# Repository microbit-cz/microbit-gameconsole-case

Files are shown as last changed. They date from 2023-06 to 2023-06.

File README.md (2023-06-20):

 # Micro:bit "Reaction game" cover for Micro:bit V2 IO Expansion Board

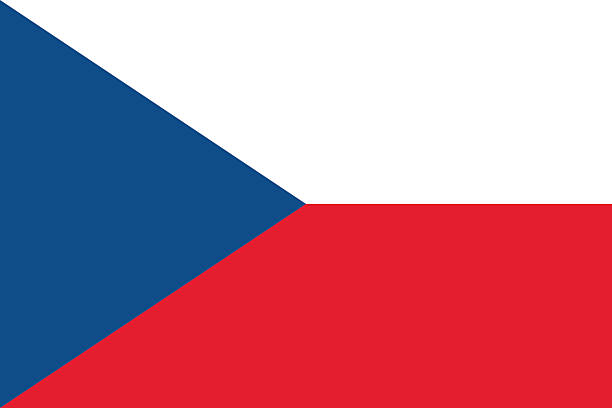
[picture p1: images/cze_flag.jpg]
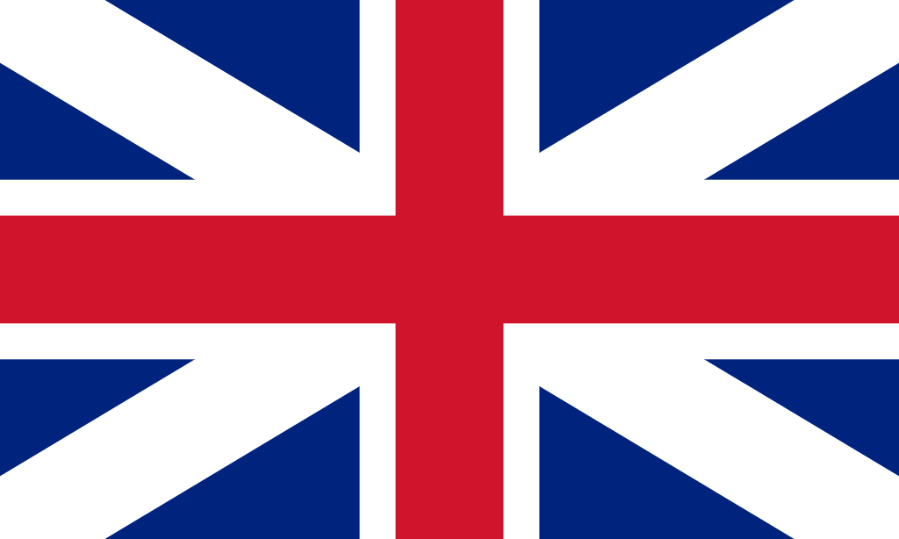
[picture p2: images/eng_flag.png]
[](./README_CZ.md) [](./README.md)

<p align="center">
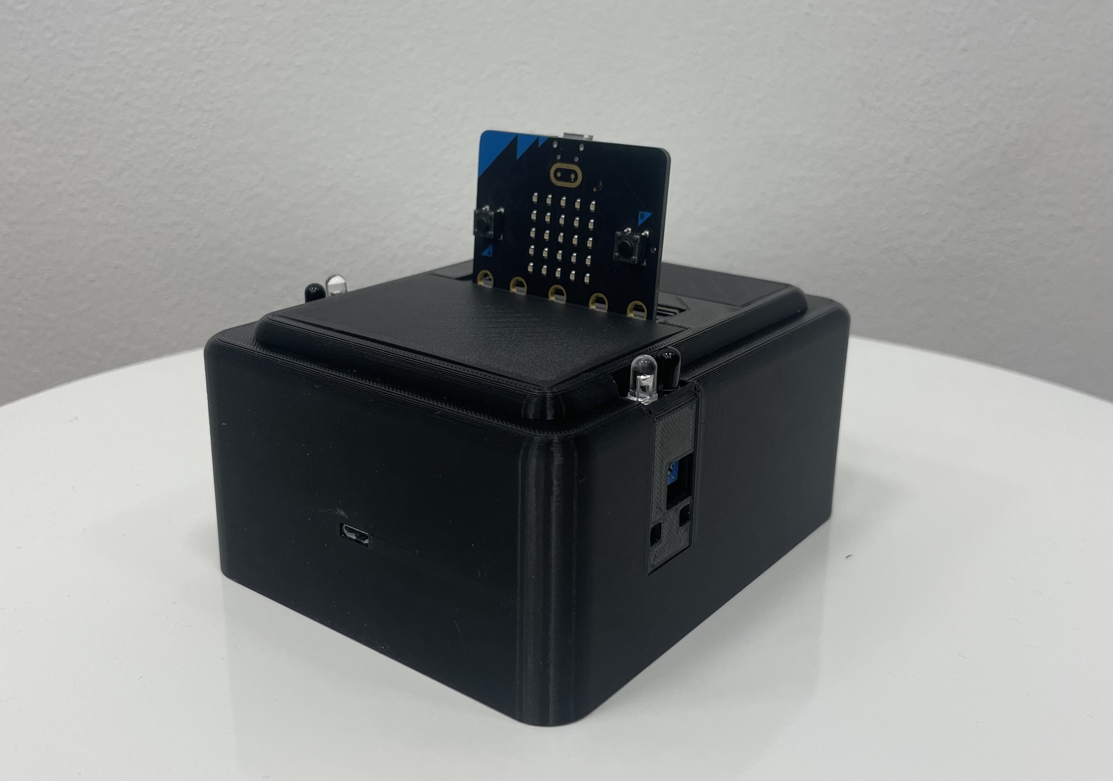
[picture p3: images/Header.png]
   
</p>

## Reaction game
### How does this game work?
A game for two players. The game engine displays an "icon" on the LEDs after a randomly long time (3-10 s) after the game restarts, and at the same time (without delay) starts a tone of 1.5 s. This indicates the start of the game. The player's task is to press the "button" before the opponent. The "button" can be pressed immediately after the LEDs are lit, while the tone is still sounding.
### Results
- Player 1 was faster → then the display shows "1"
- Faster was player 2 → then display shows "2"
- They both pressed the "button" at the same moment (within the computer's reaction time) → then the display shows "R" → Draw
- Player 1 pressed the "button" one or more times before the game started → then the display shows "B"	
- Player 2 has pressed the "button" one or more times before the game starts → then the display shows "A"
- Both players have pressed the "button" one or more times before the game starts → then the display shows "C" → Cheater
  
  [Code here](https://github.com/pslib-cz/2022-p2a-mme-pppp-Lukypop/blob/main/pxt-reaction-game-as-txt.txt)
  
## Tips & Tricks

- [Installing heat nuts](https://markforged.com/resources/blog/heat-set-inserts)
- [Cable crimping](https://ratrig.dozuki.com/Guide/11.+Cable+Crimping/80)
- [Soldering](https://www.makerspaces.com/how-to-solder/)

## What do you need?

- Micro:bit extension [Micro:bit V2 IO Expansion Board](https://www.aliexpress.com/item/1005002353248507.html)
- 2 pieces of [Insert Nut M3](https://www.aliexpress.com/item/1005004701945081.html)
- 2 pieces of [IR sensor](https://www.aliexpress.com/item/1297063929.html)
- 1 piece of [Batery Holder AA](https://www.aliexpress.com/item/1005002927831106.html)
- 1 piece of [Vertical micro USB ](https://www.aliexpress.com/item/1005002650191316.html)
- 1 piece of [Micro USB connector](https://www.aliexpress.com/item/32267930530.html)
- ~150 grams of filament ABS
- 1× 2-way cable (9 cm)
- 2× 3-way crimped cables (10 cm)
- 2× LEGO part 2780 [example](https://www.amazon.co.uk/Technic-Friction-Ridges-Lengthwise-Center/dp/B01N6WURXK/)

## Embedding parts
### Step 1:
- download and print [parts](https://github.com/pslib-cz/2022-p2a-mme-pppp-Lukypop/tree/main/parts) or [parts as STL](https://github.com/pslib-cz/2022-p2a-mme-pppp-Lukypop/tree/main/parts/STL) using a 3d printer
### Step 2:
- insert heat nuts on both sides
  
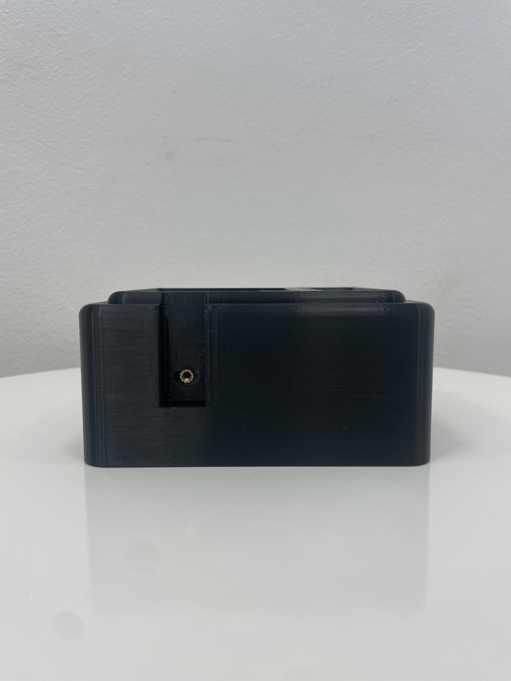
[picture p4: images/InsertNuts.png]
   

### Step 3:
- Insert lego parts into the holes
- Place Micro:bit V2 IO Expansion Board on these parts
  
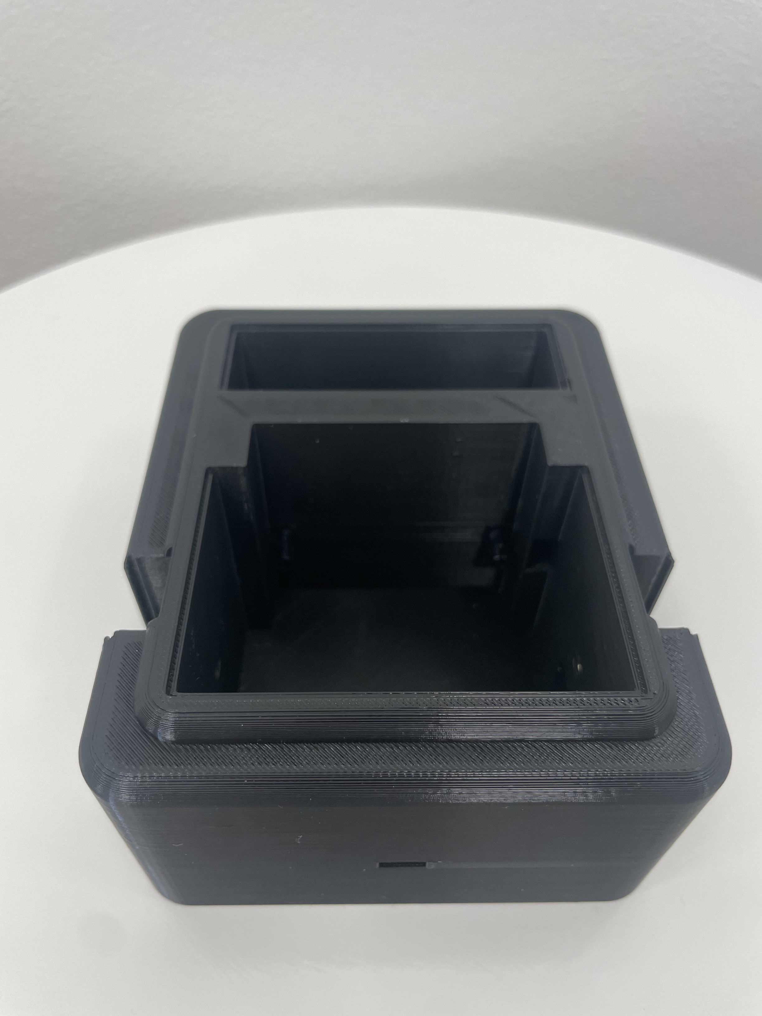
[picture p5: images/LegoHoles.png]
    
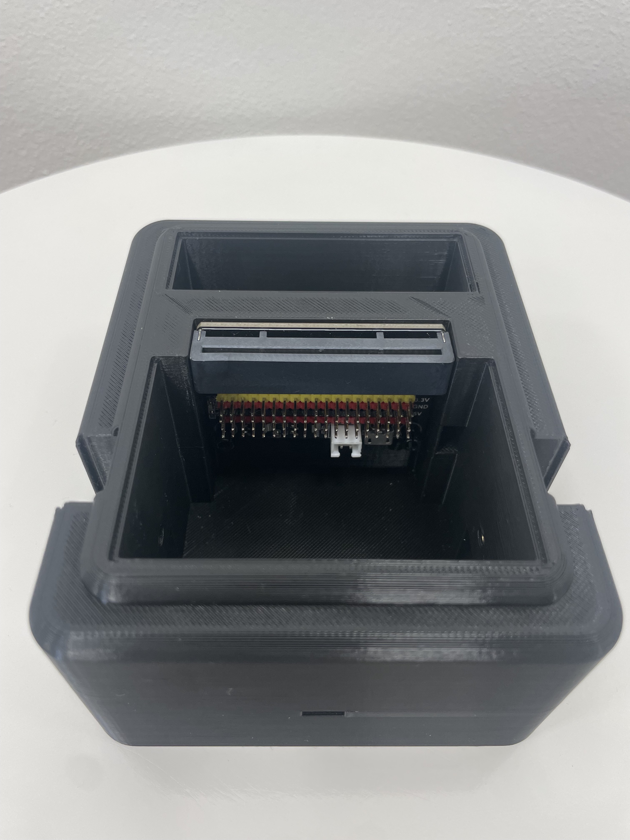
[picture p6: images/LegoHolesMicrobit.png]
    

### Step 4:
- Connect IR sensor to 3-way crimped cable and put it through hole
- Screw the M3 bolt to hold IR sensor into insert nut

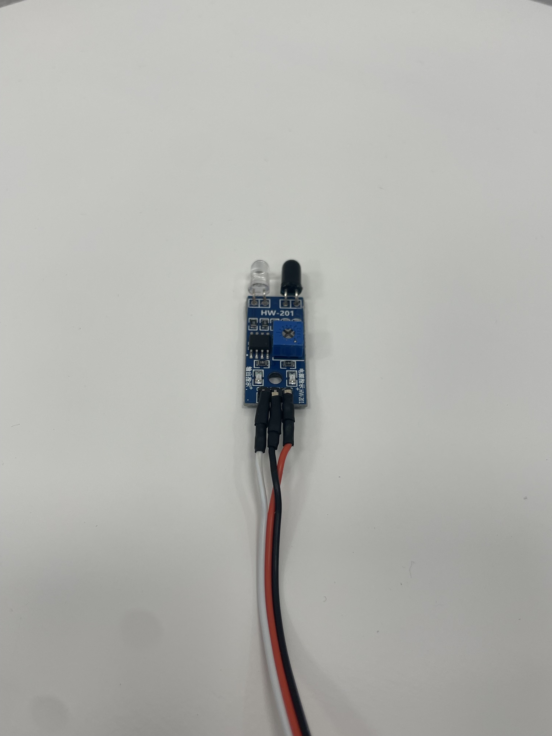
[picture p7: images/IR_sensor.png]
   
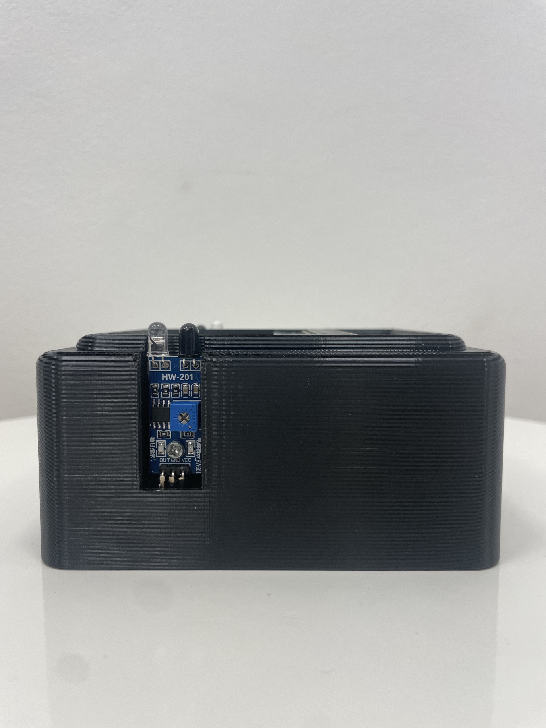
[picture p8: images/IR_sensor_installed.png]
   
 
- Slide sensor lid into thin hole
- Do "Step 4" on both sides

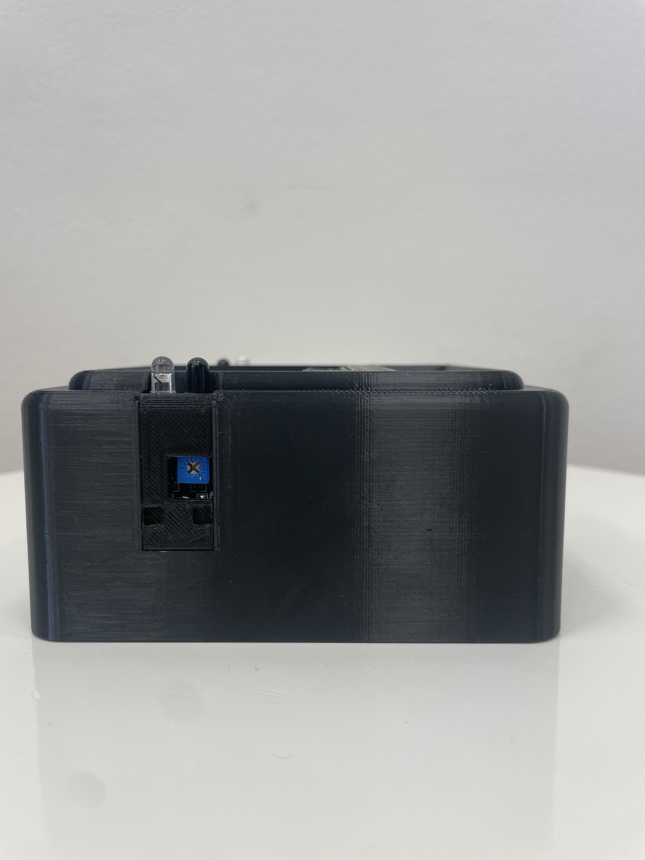
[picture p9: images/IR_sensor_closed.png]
   
  
- Connect 3-way crimped cables to Micro:bit V2 IO Expansion Board on pins: 1, 2 (see image)

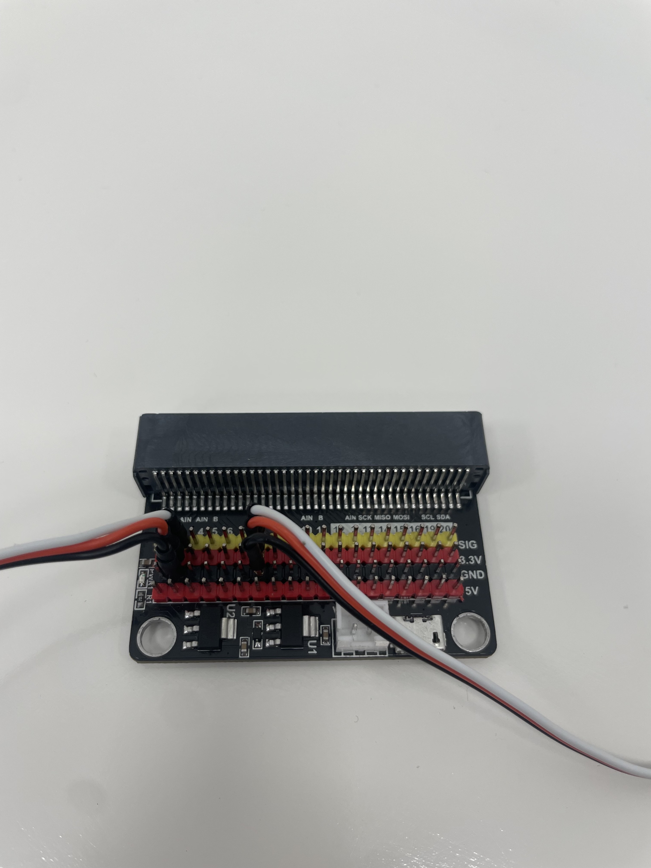
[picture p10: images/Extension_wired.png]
    
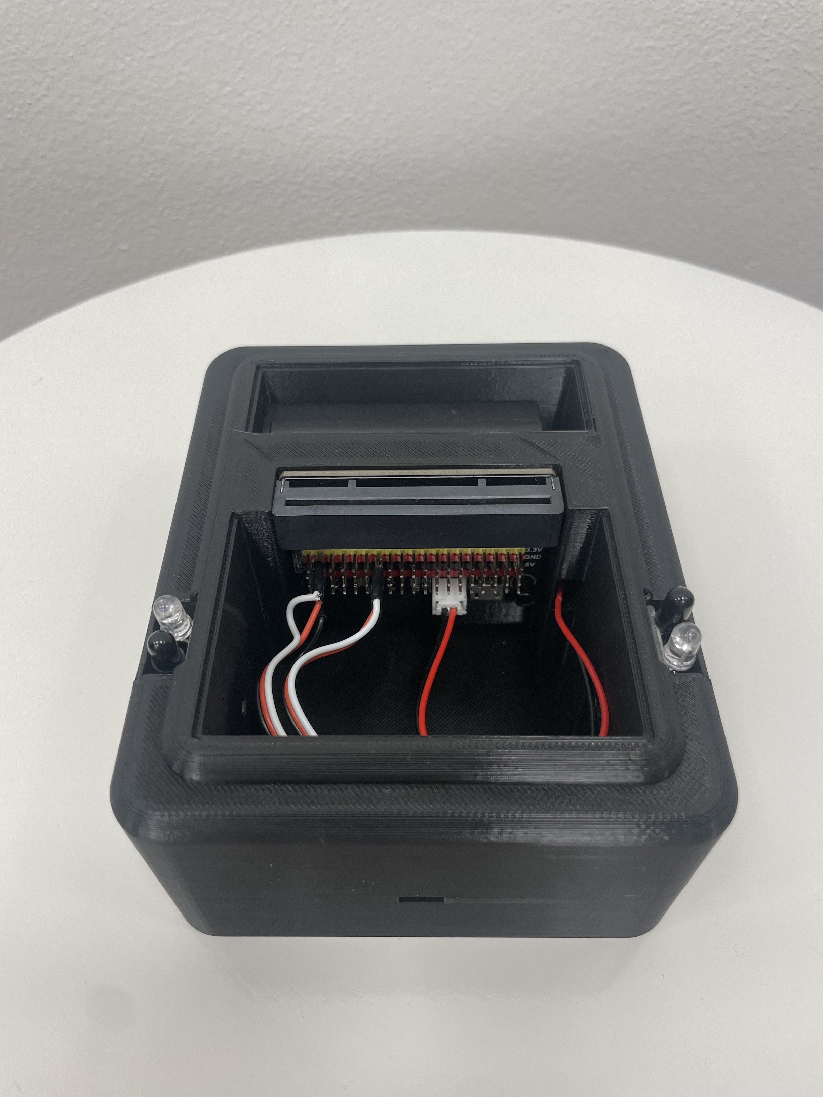
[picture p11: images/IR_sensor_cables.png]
    

### Step 5:
- Put battery holder cable through hole
- Connect it into Micro:bit V2 IO Expansion Board (into [JST-PH plug](./images/JST_plug.jpg))
- Place battery holder in storage place

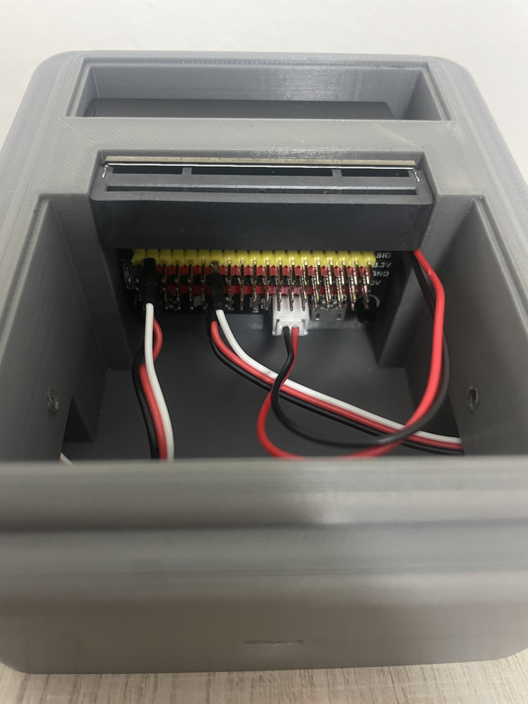
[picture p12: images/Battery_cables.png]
   
   
### Step 6:
- Connect 2-way cable with vertical micro USB plug and micro USB connector using soldering
- Be careful about + and - ([see image](https://github.com/pslib-cz/2022-p2a-mme-pppp-Lukypop/blob/main/images/micro_usb_wiring.png) if you are not sure)

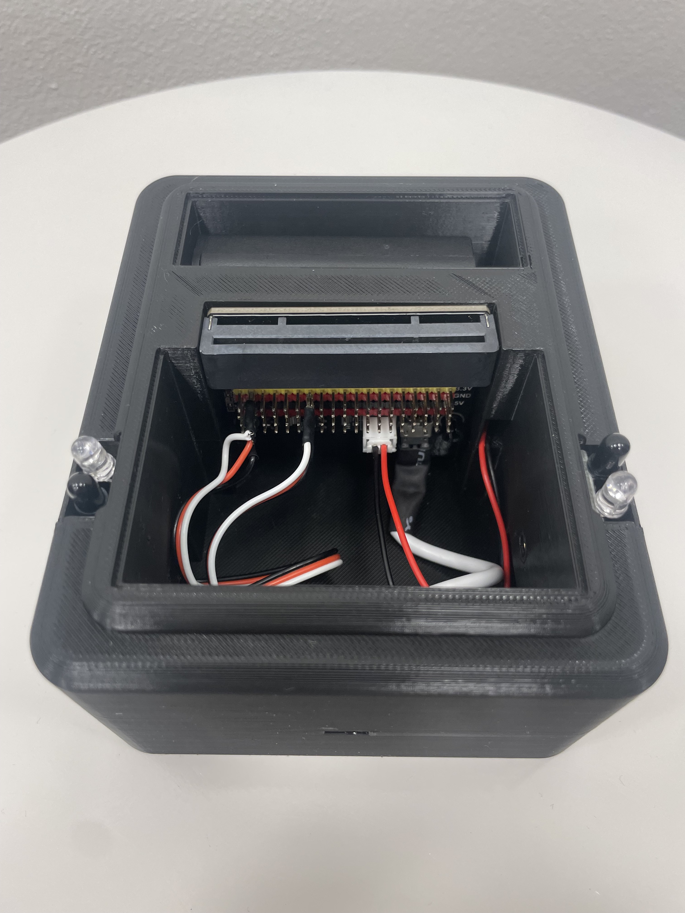
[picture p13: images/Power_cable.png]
    

- Connect micro USB into Micro:bit V2 IO Expansion Board and glue vertical micro USB plug into pre-made hole

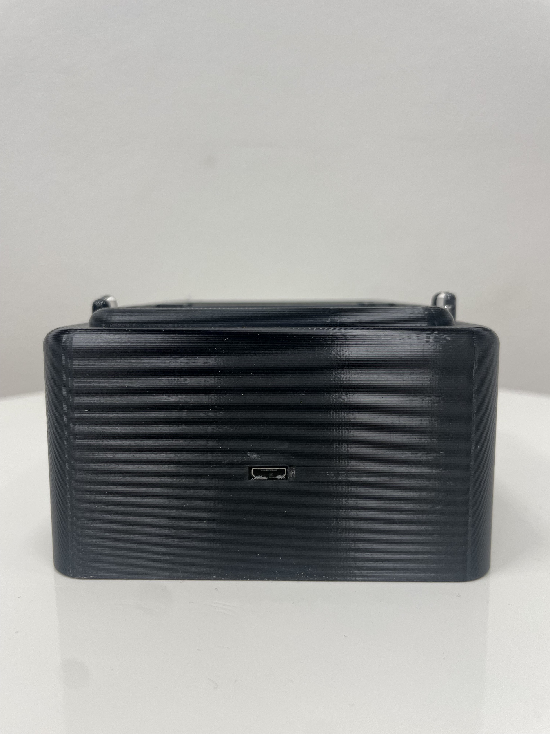
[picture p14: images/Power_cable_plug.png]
      
      
- Close both storage places with lids

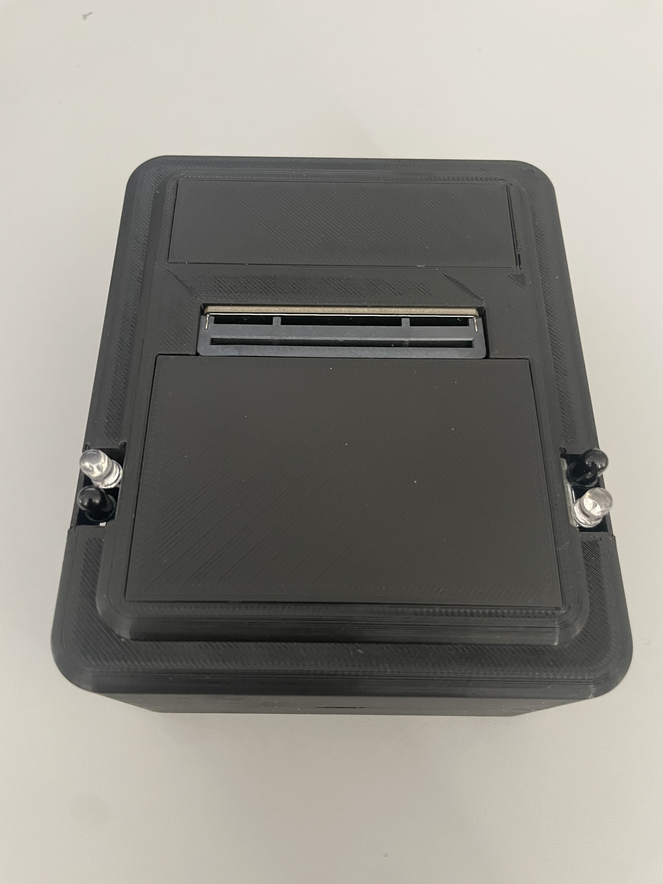
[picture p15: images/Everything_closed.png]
      
     
### Step 7:
- Upload the code to the micro:bit [code here](https://github.com/pslib-cz/2022-p2a-mme-pppp-Lukypop/blob/main/microbit-pxt-reaction-game.hex) or [as .txt here](https://github.com/pslib-cz/2022-p2a-mme-pppp-Lukypop/blob/main/pxt-reaction-game-as-txt.txt)
- You can use [Micro:bit MakeCode](https://makecode.microbit.org/) to download it into micro:bit easily

## Author
[@Lukypop](https://github.com/Lukypop)

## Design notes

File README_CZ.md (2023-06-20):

 # Pouzdro na "Postřehovou hru" pro Micro:bit V2 IO Expansion Board
 
[](./README_CZ.md) [](./README.md)

<p align="center">
   
</p>

## Postřehová hra
### Jak tato hra funguje?
Hra pro dva hráče. Herní engine po náhodně dlouhé době (3–10 s) od restartu hry zobrazí "ikonu" na ledkách a zároveň (bez prodlevy) spustí tón o délce 1,5 s. Tak je indikováno zahájení hry. Úkolem hráče je stisknout "tlačítko" dříve než soupeř. "Tlačítko" lze stisknout ihned po rozsvícení led diod, ještě v době, kdy zvuk tónu zní.
Pokud je hra zahájena, herní engine po stisku "tlačítka" zobrazí výsledek hry. Existuje 6 možných výsledků:
### Výsledky
- Rychlejší byl hráč 1 → potom display zobrazí "1"	
- Rychlejší byl hráč 2 → potom display zobrazí "2"
- Oba stiskli "tlačítko" ve stejném okamžiku (v rámci reakční doby počítače) → potom display zobrazí "R"emíza
- Hráč 1 stiskl "tlačítko" jednou nebo vícekrát ještě před zahájením hry → potom display zobrazí "B"
- Hráč 2 stiskl "tlačítko" jednou nebo vícekrát ještě před zahájením hry → potom display zobrazí "A"
- Oba hráči stiskli "tlačítko" jednou nebo vícekrát ještě před zahájením hry → potom display zobrazí "C"heater
  [kód zde](https://github.com/pslib-cz/2022-p2a-mme-pppp-Lukypop/blob/main/pxt-reaction-game-as-txt.txt)
  
## Tipy a Triky
- [Vložení tepelné matice](https://markforged.com/resources/blog/heat-set-inserts)
- [Krimpování kabelů](https://ratrig.dozuki.com/Guide/11.+Cable+Crimping/80)
- [Pájení](https://www.makerspaces.com/how-to-solder/)

## Co budeme potřebovat?
- Micro:bit rozšíření [Micro:bit V2 IO Expansion Board](https://www.aliexpress.com/item/1005002353248507.html)
- 2 kusy [Insert matice M3](https://www.aliexpress.com/item/1005004701945081.html)
- 2 kusy [IR senzor](https://www.aliexpress.com/item/1297063929.html)
- 1 kusy [Pouzdro na baterie AA](https://www.aliexpress.com/item/1005002927831106.html)
- 1 kus [Vertikální micro USB ](https://www.aliexpress.com/item/1005002650191316.html)
- 1 kus [Micro USB konektor](https://www.aliexpress.com/item/32267930530.html)
- ~150 gramů filamentu ABS
- 1× 2-žilný kabel (9 cm)
- 2× 3-žilné krimpované kabely (10 cm)
- 2× LEGO součástka 2780 [příklad](https://www.amazon.co.uk/Technic-Friction-Ridges-Lengthwise-Center/dp/B01N6WURXK/)

## Spojení součástek do sebe
### Krok 1:
- stáhněte a vytiskněte [součásky](https://github.com/pslib-cz/2022-p2a-mme-pppp-Lukypop/tree/main/parts) nebo [součástky jako STL](https://github.com/pslib-cz/2022-p2a-mme-pppp-Lukypop/tree/main/parts/STL) pomocí 3D tiskárny
### Krok 2:
- vložte z obou stran insertové matice
  
   

### Krok 3:
- Vložte lego spojky do děr v hlavním dílu
- Umístěte Micro:bit V2 IO Expansion Board na tyto spojky
  
   
   

### Krok 4:
- Propojte IR senzor pomocí krimpovaného 3-žilného kabelu a protáhněte jej dírou v hlavním dílu
- Přišroubujte IR senzor pomocí šroubu M3 do insertové matice

   
   
 
- Zasuňte krytku na senzor do drážky
- Udělejte "Krok 4" na obou stranách 

   
  
- Připojte krimpovaný 3-žilný kabel do Micro:bit V2 IO Expansion Board na piny: 1, 2 (viz obrázek)

   
   

### Krok 5:
- Protáhněte kabel od pouzdra na baterie dírou v hlavním díle
- Zapojte jej do Micro:bit V2 IO Expansion Board (do [JST-PH plug](./images/JST_plug.jpg))
- Vložte pouzdro na baterie do zadní části, ve které je na to připravemé místo 

   
   
### Krok 6:
- Propojte dvoužilný kabel s vertikálním plugem micro USB a konektorem micro USB pomocí pájení
- Buďte opatrní na + a - ([viz obrázek](https://github.com/pslib-cz/2022-p2a-mme-pppp-Lukypop/blob/main/images/micro_usb_wiring.png) pokud si nejste jist)

   

- Připojte micro USB do Micro:bit V2 IO Expansion Board a přilepte vertikální micro USB plug do před-dělané díry

     
     
- Zavřete všechny prostory pomocí víček

     
     
### Krok 7:
- Nahrajte kód do micro:bitu [kód zde](https://github.com/pslib-cz/2022-p2a-mme-pppp-Lukypop/blob/main/microbit-pxt-reaction-game.hex) nebo [jako .txt zde](https://github.com/pslib-cz/2022-p2a-mme-pppp-Lukypop/blob/main/pxt-reaction-game-as-txt.txt)
- Můžete použít [Micro:bit MakeCode](https://makecode.microbit.org/) na snadné stažení kódu do micro:bitu

## Autor
[@Lukypop](https://github.com/Lukypop)

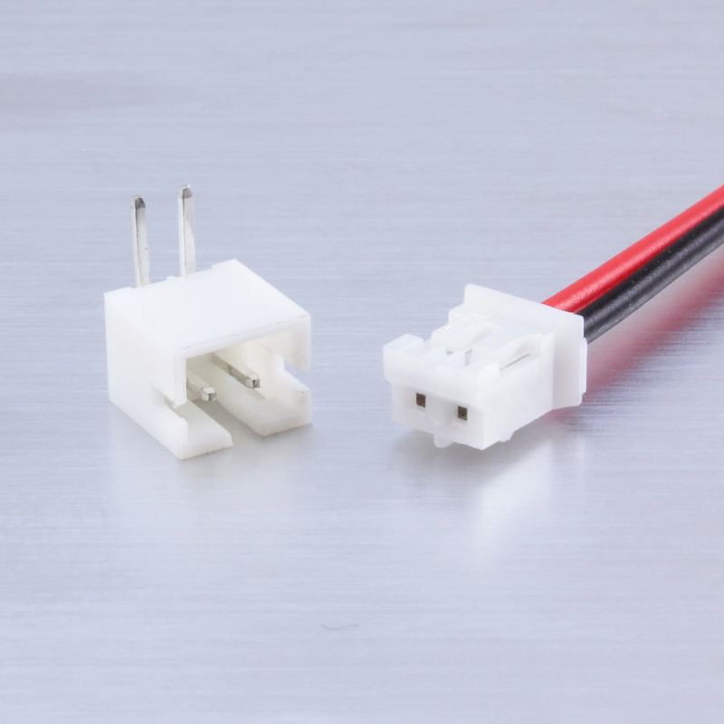
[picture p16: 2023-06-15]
images/JST_plug.jpg

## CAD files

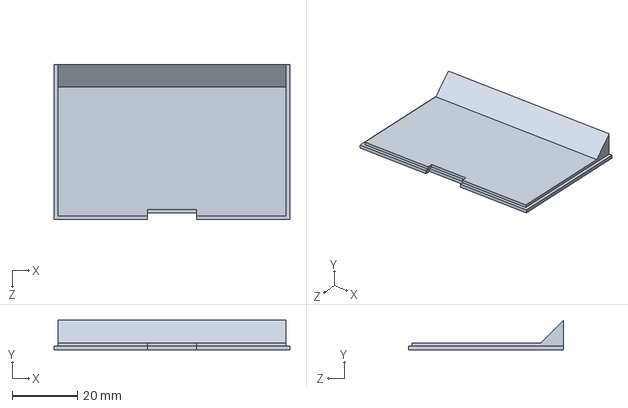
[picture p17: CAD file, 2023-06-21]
parts/ReactionGame_box_lid.SLDPRT
72.4 x 9.20 x 47.7 mm

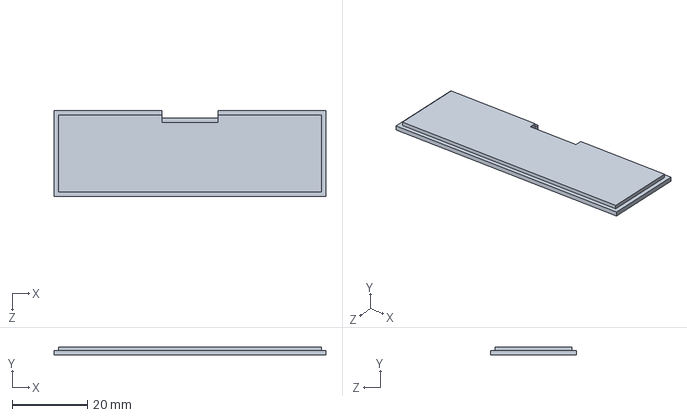
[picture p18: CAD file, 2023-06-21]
parts/ReactionGame_battery_lid.SLDPRT
72.4 x 2.20 x 22.9 mm

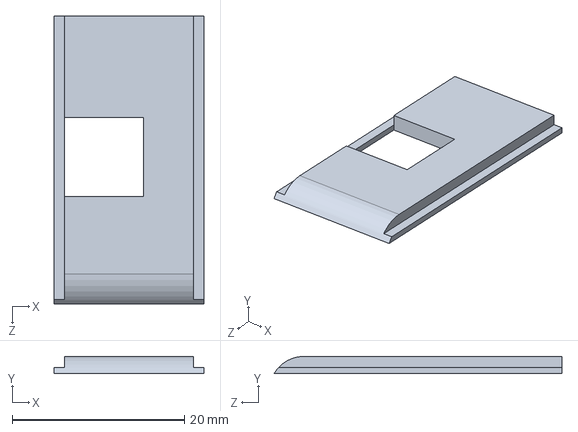
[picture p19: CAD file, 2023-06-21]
parts/ReactionGame_sensor_lid.SLDPRT
17.4 x 2.00 x 33.5 mm

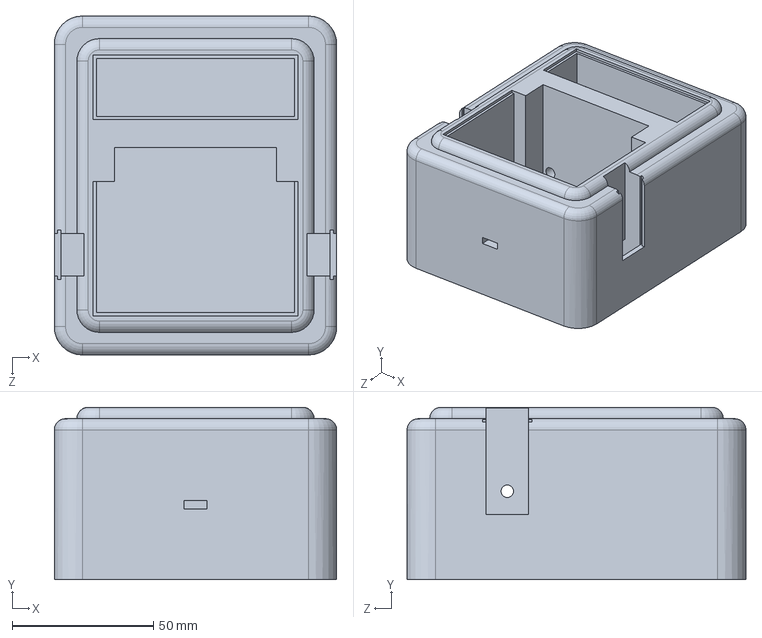
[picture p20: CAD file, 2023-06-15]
parts/ReactionGame_box.SLDPRT
100.0 x 61.0 x 120.0 mm

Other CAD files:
parts/STL/ReactionGame_battery_lid.STL
parts/STL/ReactionGame_box.STL
parts/STL/ReactionGame_box_lid.STL
parts/STL/ReactionGame_sensor_lid.STL

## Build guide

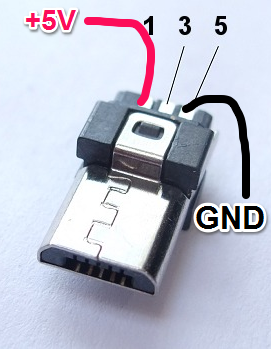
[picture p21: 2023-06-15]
images/micro_usb_wiring.png

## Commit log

2023-06-06 Update README.md
    cable creampie
2023-06-20 mikeš
    [ReactionGame_battery_lid.SLDPRT, ReactionGame_battery_lid.STL, ReactionGame_box.SLDPRT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]
2023-06-21 lids change
    [ReactionGame_battery_lid.SLDPRT, ReactionGame_battery_lid.STL, ReactionGame_box.SLDPRT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]
